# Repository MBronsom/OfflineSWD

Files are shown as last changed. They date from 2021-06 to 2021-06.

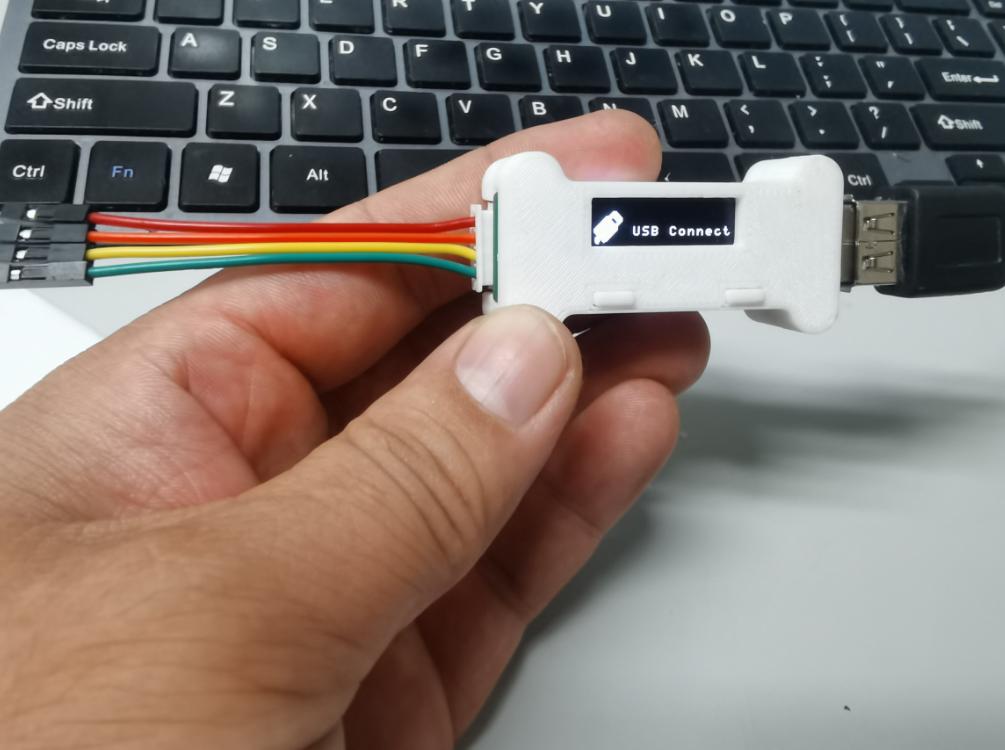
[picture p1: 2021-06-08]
Image/model_1.png

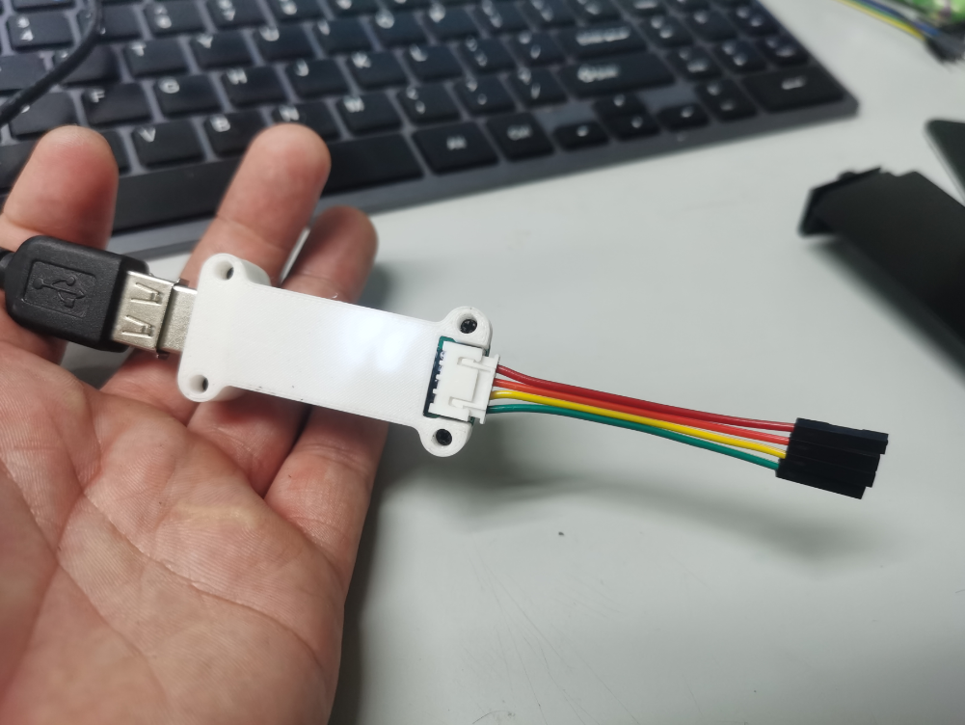
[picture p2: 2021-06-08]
Image/model_2.png

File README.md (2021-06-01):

# SWD离线烧写器
本项目使用STM32F103RET6作为主控，基于ST官方CMSIS-DAP项目进行修改，实现可脱机、可去读保护烧写（因项目暂时只有F103系列脱机烧写需求，所以暂时只添加了F103的烧写算法）。
#### <br>
## 项目功能
#### 1.使用8M FLASH，可使用虚拟U盘向FLASH放置HEX文件或BIN文件进行烧写（BIN较快）
#### 2.可去除目标板的读保护，直接烧写（烧写后可能需要手动重启）
#### 3.支持手动切换模式，使离线烧写器支持DAP仿真
#### 4.安装驱动后可支持虚拟USB转TTL
#### 5.可离线使用串口调试功能（仅支持英文及常用数字符号）
#### <br>
## 使用教程
#### 1.长按SELECT键开机可进入DAP仿真模式，屏幕上显示DAP-CONNECT
#### 2.直接插入电脑USB端口可向离线烧写器放入相关烧写文件，并可使用虚拟串口功能
#### 3.连接目标板开机，选择文件后选择FLASH后即可进行烧写
#### 4.选择“>>”，进入DEBUG MODE后选择ENTER即可进行离线串口调试
#### <br>
## 其他
#### 当前版本项目已包含所有所需外部支持包，无需额外包含其他支持包。
## 项目意见
#### 如果项目有问题或者有新功能需求，欢迎向作者提交意见！
#### 欢迎加入QQ交流群 群号:912015729

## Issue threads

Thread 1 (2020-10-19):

lack of "Driver_USART.h

qiujianqin, 2020-10-19:
..\HARDWARE\DAP\SWO.c(26): error:  #5: cannot open source input file "Driver_USART.h": No such file or directory

MBronsom, 2020-10-19:
请包含ARM CMSIS包中的以下目录
Packs\ARM\CMSIS\5.6.0\CMSIS
Packs\ARM\CMSIS\5.6.0\CMSIS\Include

qiujianqin, 2020-10-19:
按照提示操作已经解决。编译无error

MBronsom, 2020-10-19:
还有其他问题欢迎提出

Closed 2020-10-19.

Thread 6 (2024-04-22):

第一次烧写正常，目标断电后不能再烧写

ssyqwer, 2024-04-22:
第一次烧写正常，目标断电后不能再烧写，程序卡住
    if(0 == swd_flash_syscall_exec(&flash_algo.sys_call_s, flash_algo.init, flash_start, 0, 0, 0))
        {
            return ERROR_INIT;
        }

uint8_t swd_flash_syscall_exec(const program_syscall_t *sysCallParam, uint32_t entry, uint32_t arg1, uint32_t arg2, uint32_t arg3, uint32_t arg4)
{
    DEBUG_STATE state = {{0}, 0};
    // Call flash algorithm function on target and wait for result.
    state.r[0]     = arg1;                   // R0: Argument 1
    state.r[1]     = arg2;                   // R1: Argument 2
    state.r[2]     = arg3;                   // R2: Argument 3
    state.r[3]     = arg4;                   // R3: Argument 4
    state.r[9]     = sysCallParam->static_base;    // SB: Static Base
    state.r[13]    = sysCallParam->stack_pointer;  // SP: Stack Pointer
    state.r[14]    = sysCallParam->breakpoint;     // LR: Exit Point
    state.r[15]    = entry;                        // PC: Entry Point
    state.xpsr     = 0x01000000;          // xPSR: T = 1, ISR = 0

    if (!swd_write_debug_state(&state)) {
        return 0;
    }

    if (!swd_wait_until_halted()) {
        return 0;
    }

    if (!swd_read_core_register(0, &state.r[0])) {
        return 0;
    }

    // Flash functions return 0 if successful.
    if (state.r[0] != 0) {
        return 0;
    }

    return 1;
}

static uint8_t swd_wait_until_halted(void)
{
    // Wait for target to stop
    uint32_t val, i, timeout = MAX_TIMEOUT;

    for (i = 0; i < timeout; i++) {

        if (!swd_read_word(DBG_HCSR, &val)) {
            return 0;
        }
        if (val & S_HALT) {
            return 1;
        }
    }

    return 0;
}
卡在最后一个函数，请问怎么解决

MBronsom, 2024-07-11:
不好意思回复晚了，有点没理解，你的意思是——第一次烧写后，后续都无法继续进行烧写了？还是其他的意思？

ssyqwer, 2024-07-11:
不好意思，这里是我的flash被保护问题，已经解决，感谢感谢

MBronsom, 2024-07-11:
好的👌

Closed 2024-07-11.

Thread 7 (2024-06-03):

离线模式hex转bin有bug

ssyqwer, 2024-06-03:
hex转bin的方式有些问题，如果遇到04类型发生地址跳转，那么按照1k字节写入的数据就会发生地址和数据对不上的情况，应该加上末尾数据填充和新的地址定位

MBronsom, 2024-07-11:
我会进行检查，耐心等待一下～

MBronsom, 2024-07-12:
我看了一下代码，是有对04类型的处理的。如果你那能够复现，能帮忙提供一下烧录的hex文件和导出的Flash，我来检查一下具体问题

ssyqwer, 2024-07-12:
不好意思，hex文件不方便提供，可以给flash最后一页写一些数据然后生成hex文件应该可以复现，我是用j-flash导出的flash和原来的hex做对比

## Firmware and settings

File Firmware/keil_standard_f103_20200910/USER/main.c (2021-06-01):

#include "main.h"

/***********************文件系统使用定义************************/
FIL fnew;													/* file objects */
FILINFO FileInfo;
DIR DirInfo;
FATFS fs;													/* Work area (file system object) for logical drives */
FRESULT Res; 
UINT br, bw;            					/* File R/W count */

/***********************变量定义************************/
char rData[1024] = "";
u8 readflag = 1;
u32 addr = 0;
u32 i = 0;
u32 select = 0;
u8 breakDebug = 0;
u8 debugMode = 0;
uint16_t bytesread;
u8 Logo[] = "BRONSON";

/***********************主函数************************/
 int main(void)
 {
	 Init_device(); //初始化设备
	 Draw_Logo(); //绘制LOGO
	 Draw_Menu(); //绘制菜单
	 while(1);
}
 
/***********************初始化设备************************/
void Init_device()
{
	NVIC_PriorityGroupConfig(NVIC_PriorityGroup_2); //优先级调整
	delay_init(); //初始化延时
	Key_Init(); //按键初始化
	W25QXX_Init(); //初始化Flash芯片
	f_mount(0,&fs); //初始化文件系统
	OLED_Init(); //初始化OLED  
	OLED_Clear(); //清空OLED屏幕
	LED_Init();
	if(Scan_Key() == 1 ){ //按住SELTCT开机进入CMSIS-DAP模式
		Draw_Logo(); //绘制LOGO
		OLED_DrawBMP(0,0,34,34,USBLogo); //绘制图标
		OLED_ShowString(38,1,"DAP Connect",1,0); //绘制提示词
		Init_DAPUSB(); //初始化DAP
		Do_DAPUSB(); //DAP循环
	}
	else{
		Set_System(); //设置USB系统
	  Set_USBClock(); //设置USB时钟
	  USB_Interrupts_Config(); //设置USB中断
	  USB_Init(); //初始化USB
	}
}

/***********************绘制LOGO************************/
void Draw_Logo(){
	 u8 i;
	 for(i=0;i<7;i++){
     OLED_ShowChar(34+i*8,1,Logo[i],1);
	   delay_ms(15);
	 }
	 delay_ms(1000);
	 OLED_Clear();
}

/***********************绘制菜单************************/
void Draw_Menu(){
	if(bDeviceState != UNCONNECTED){
		OLED_DrawBMP(0,0,34,34,USBLogo);
		OLED_ShowString(38,1,"USB Connect",1,0);
	}
  else{
		OLED_DrawBMP(0,0,33,33,FlashLogo);
		//自动烧写模式（将命名为AUTO.bin的文件放入根目录）
		if(f_open(&fnew, (const TCHAR*)"AUTO.bin",FA_READ ) == FR_OK){ 
		  OLED_ShowString(45,-1,"AUTO FLASH",1,0);
		  while(!FLASH_SWD("AUTO.bin")){
		    u8 WaitTips[] = "...";
			  OLED_ShowString(45,1,"          ",1,0);
			  OLED_ShowString(45,2,"WAIT",1,1);
			  for(i=0;i<3;i++){
          OLED_ShowChar(69+i*6,2,WaitTips[i],1);
	        delay_ms(200);
	      }
			  OLED_ShowString(45,2,"       ",1,1);
		  }
			OLED_ShowString(98,2,"BACK",1,1);
			select = 0;
			while(1)
			{
				if(Scan_Key() == 1){
					select ++;
					if(select == 1) {
						OLED_ShowString(98,2,"    ",1,1);
						OLED_ShowString(98,2,"BACK",0,1);
					}
					else{
						OLED_ShowString(98,2,"    ",1,1);
						OLED_ShowString(98,2,"BACK",1,1);
					}
					if(select == 2) select = 0;
				}
				if(Scan_Key() == 2){
					if(select == 1) break;
				}
			}
			OLED_Clear();
		  OLED_DrawBMP(0,0,33,33,FlashLogo);
		}
		Draw_Main(); //进入主菜单
	}
}

/***********************绘制主菜单************************/
void Draw_Main(){
	f_unlink("0:/write.bin");
	if(f_opendir(&DirInfo,(const TCHAR*)"0:") == FR_OK)/* 打开文件夹目录成功，目录信息已经在dir结构体中保存 */
  {
      if(f_readdir(&DirInfo, &FileInfo) == FR_OK)  /* 读文件信息到文件状态结构体中 */
      {
				f_readdir(&DirInfo, &FileInfo);
				OLED_ShowString(45,1,FileInfo.fname,1,1);
			}
	}		
	OLED_ShowString(45,-1,"SELECT HEX",1,0);
	OLED_ShowString(45,0,"----------",1,0);
	OLED_ShowString(110,1,">>",1,1);
	OLED_ShowString(92,2,"FLASH",1,1);
	select = 0;
	while(1)
	{
		if(Scan_Key() == 1){
			select ++;
			if(select == 4) select = 0;
			switch(select){
				case 0:
				  OLED_ShowString(45,1,FileInfo.fname,1,1);
					OLED_ShowString(110,1,">>",1,1);
				  OLED_ShowString(92,2,"FLASH",1,1);
				  break;
				case 1:
				  OLED_ShowString(45,1,FileInfo.fname,0,1);
					OLED_ShowString(110,1,">>",1,1);
				  OLED_ShowString(92,2,"FLASH",1,1);
				  break;
				case 2:
				  OLED_ShowString(45,1,FileInfo.fname,1,1);
					OLED_ShowString(110,1,">>",0,1);
				  OLED_ShowString(92,2,"FLASH",1,1);
				  break;
				case 3:
				  OLED_ShowString(45,1,FileInfo.fname,1,1);
					OLED_ShowString(110,1,">>",1,1);
				  OLED_ShowString(92,2,"FLASH",0,1);
				  break;
			}
		}
		if(Scan_Key() == 2){
			switch(select){
				case 1: //选择文件
					f_readdir(&DirInfo, &FileInfo);
				  OLED_ShowString(45,1,"          ",1, 1);
				  OLED_ShowString(45,1,FileInfo.fname,0,1);
				  OLED_ShowString(110,1,">>",1,1);
				  if(!FileInfo.fname[0]){
						f_opendir(&DirInfo,(const TCHAR*)"0:");
						f_readdir(&DirInfo, &FileInfo);
						f_readdir(&DirInfo, &FileInfo);
						OLED_ShowString(45,1,"          ",1,1);
				    OLED_ShowString(45,1,FileInfo.fname,0,1);
				    OLED_ShowString(110,1,">>",1,1);
					}
					break;
				case 2: //进入调试模式
					select = 0;
					OLED_Clear();
				  OLED_DrawBMP(0,0,32,32,DebugLogo);
				  OLED_ShowString(45,-1,"DEBUG MODE",1,0);
					OLED_ShowString(45,0,"----------",1,0);
				  OLED_ShowString(45,2,"<<",1,1);
				  OLED_ShowString(92,2,"ENTER",1,1);
				  while(1){
						if(Scan_Key() == 1){
							select ++;
							if(select == 3) select = 0;
							switch(select){
								case 0:
									OLED_ShowString(45,2,"<<",1,1);
								  OLED_ShowString(92,2,"ENTER",1,1);
									break;
								case 1:
									OLED_ShowString(45,2,"<<",0,1);
								  OLED_ShowString(92,2,"ENTER",1,1);
									break;
								case 2:
									OLED_ShowString(45,2,"<<",1,1);
								  OLED_ShowString(92,2,"ENTER",0,1);
									break;
							}
							delay_ms(100);
						}
						
						if(Scan_Key() == 2){
							switch(select){
									case 1: //返回上一页面
										OLED_Clear();
										OLED_DrawBMP(0,0,33,33,FlashLogo);
										if(f_opendir(&DirInfo,(const TCHAR*)"0:") == FR_OK)/* 打开文件夹目录成功，目录信息已经在dir结构体中保存 */
										{
											if(f_readdir(&DirInfo, &FileInfo) == FR_OK)  /* 读文件信息到文件状态结构体中 */
											{
												 f_readdir(&DirInfo, &FileInfo);
												 OLED_ShowString(45,1,FileInfo.fname,1,1);
											}
										}		
										OLED_ShowString(45,-1,"SELECT HEX",1,0);
										OLED_ShowString(45,0,"----------",1,0);
										OLED_ShowString(110,1,">>",1,1);
										OLED_ShowString(92,2,"FLASH",1,1);
										select = 0;
										breakDebug = 1;
										break;
									case 2: //确认进入调试模式
										select = 0;
									  debugMode = 1;
										OLED_Clear();
										OLED_ShowString(98,2,"BACK",1,1);
									  while(1)
										{
											if(Scan_Key() == 1){
												select ++;
												if(select == 1) {
													OLED_ShowString(98,2,"    ",1,1);
													OLED_ShowString(98,2,"BACK",0,1);
												}
												else{
													OLED_ShowString(98,2,"    ",1,1);
													OLED_ShowString(98,2,"BACK",1,1);
												}
												if(select == 2) select = 0;
											}
											if(Scan_Key() == 2){
												if(select == 1) break;
											}
										}
										select = 0;
										debugMode = 0;
										OLED_Clear();
										OLED_DrawBMP(0,0,32,32,DebugLogo);
										OLED_ShowString(45,-1,"DEBUG MODE",1,0);
										OLED_ShowString(45,0,"----------",1,0);
										OLED_ShowString(45,2,"<<",1,1);
										OLED_ShowString(92,2,"ENTER",1,1);
										break;
								}
						}
						if(breakDebug){
							breakDebug = 0;
							break;
						}
					}
					break;
				case 3: //进行烧写
					if(strstr(FileInfo.fname,"HEX")) { //HEX文件烧写模式
						OLED_Clear();
		        OLED_DrawBMP(0,0,33,33,FlashLogo);
						if(f_open(&fnew, (const TCHAR*)FileInfo.fname,FA_READ ) == FR_OK){
		          OLED_ShowString(45,-1,"HEX  FLASH",1,0);
							if(HexFormatUncode(FileInfo.fname)!=1){
								OLED_ShowString(45,2,"          ",1,0);
			          OLED_ShowString(45,2,"ERR",1,0);
								select = 0;
			          while(1)
			          {
				          if(Scan_Key() == 1){
					          select ++;
					          if(select == 1) {
						          OLED_ShowString(98,2,"    ",1,1);
						          OLED_ShowString(98,2,"BACK",0,1);
					          }
					          else{
					        	  OLED_ShowString(98,2,"    ",1,1);
						          OLED_ShowString(98,2,"BACK",1,1);
					          }
					           if(select == 2) select = 0;
				          }
				          if(Scan_Key() == 2){
					          if(select == 1) break;
				          }
			          }
			          OLED_Clear();
		            OLED_DrawBMP(0,0,33,33,FlashLogo);
							  if(f_opendir(&DirInfo,(const TCHAR*)"0:") == FR_OK)/* 打开文件夹目录成功，目录信息已经在dir结构体中保存 */
                {
                  if(f_readdir(&DirInfo, &FileInfo) == FR_OK)  /* 读文件信息到文件状态结构体中 */
                  {
				             f_readdir(&DirInfo, &FileInfo);
				             OLED_ShowString(45,1,FileInfo.fname,1,1);
			            }
	              }		
	              OLED_ShowString(45,-1,"SELECT HEX",1,0);
	              OLED_ShowString(45,0,"----------",1,0);
	              OLED_ShowString(110,1,">>",1,1);
	              OLED_ShowString(92,2,"FLASH",1,1);
	              select = 0;
							}
							else{
							  delay_ms(100);
							  OLED_ShowString(45,1,"          ",1,0);
							  OLED_ShowString(45,2,"          ",1,0);
		            while(!FLASH_SWD("write.bin")){
		              u8 WaitTips[] = "...";
			            OLED_ShowString(45,1,"          ",1,0);
			            OLED_ShowString(45,2,"WAIT",1,1);
			            for(i=0;i<3;i++){
                    OLED_ShowChar(69+i*6,2,WaitTips[i],1);
	                  delay_ms(200);
	                }
			            OLED_ShowString(45,2,"       ",1,1);
		            }
								f_unlink("0:/write.bin");
			          OLED_ShowString(98,2,"BACK",1,1);
			          select = 0;
			          while(1)
			          {
				          if(Scan_Key() == 1){
					          select ++;
					          if(select == 1) {
						          OLED_ShowString(98,2,"    ",1,1);
						          OLED_ShowString(98,2,"BACK",0,1);
					          }
					          else{
					        	  OLED_ShowString(98,2,"    ",1,1);
						          OLED_ShowString(98,2,"BACK",1,1);
					          }
					           if(select == 2) select = 0;
				          }
				          if(Scan_Key() == 2){
					          if(select == 1) break;
				          }
			          }
			          OLED_Clear();
		            OLED_DrawBMP(0,0,33,33,FlashLogo);
							  if(f_opendir(&DirInfo,(const TCHAR*)"0:") == FR_OK)/* 打开文件夹目录成功，目录信息已经在dir结构体中保存 */
                {
                  if(f_readdir(&DirInfo, &FileInfo) == FR_OK)  /* 读文件信息到文件状态结构体中 */
                  {
				             f_readdir(&DirInfo, &FileInfo);
				             OLED_ShowString(45,1,FileInfo.fname,1,1);
			            }
	              }		
	              OLED_ShowString(45,-1,"SELECT HEX",1,0);
	              OLED_ShowString(45,0,"----------",1,0);
	              OLED_ShowString(110,1,">>",1,1);
	              OLED_ShowString(92,2,"FLASH",1,1);
	              select = 0;
		          }
					  }
					}
				  else{ //BIN文件烧写模式
						OLED_Clear();
		        OLED_DrawBMP(0,0,33,33,FlashLogo);
						if(f_open(&fnew, (const TCHAR*)FileInfo.fname,FA_READ ) == FR_OK){
		          OLED_ShowString(45,-1,"BIN  FLASH",1,0);
		          while(!FLASH_SWD(FileInfo.fname)){
		            u8 WaitTips[] = "...";
			          OLED_ShowString(45,1,"          ",1,0);
			          OLED_ShowString(45,2,"WAIT",1,1);
			          for(i=0;i<3;i++){
                  OLED_ShowChar(69+i*6,2,WaitTips[i],1);
	                delay_ms(200);
	              }
			          OLED_ShowString(45,2,"       ",1,1);
		          }
			        OLED_ShowString(98,2,"BACK",1,1);
			        select = 0;
			        while(1)
			        {
				        if(Scan_Key() == 1){
					        select ++;
					        if(select == 1) {
						        OLED_ShowString(98,2,"    ",1,1);
						        OLED_ShowString(98,2,"BACK",0,1);
					        }
					        else{
					        	OLED_ShowString(98,2,"    ",1,1);
						        OLED_ShowString(98,2,"BACK",1,1);
					        }
					         if(select == 2) select = 0;
				        }
				        if(Scan_Key() == 2){
					        if(select == 1) break;
				        }
			        }
			        OLED_Clear();
		          OLED_DrawBMP(0,0,33,33,FlashLogo);
							if(f_opendir(&DirInfo,(const TCHAR*)"0:") == FR_OK)/* 打开文件夹目录成功，目录信息已经在dir结构体中保存 */
              {
                if(f_readdir(&DirInfo, &FileInfo) == FR_OK)  /* 读文件信息到文件状态结构体中 */
                {
				           f_readdir(&DirInfo, &FileInfo);
				           OLED_ShowString(45,1,FileInfo.fname,1,1);
			          }
	            }		
	            OLED_ShowString(45,-1,"SELECT HEX",1,0);
	            OLED_ShowString(45,0,"----------",1,0);
	            OLED_ShowString(110,1,">>",1,1);
	            OLED_ShowString(92,2,"FLASH",1,1);
	            select = 0;
		        }
					}
					break;
			}
		}
	}
}

/***********************离线SWD烧写************************/
u8 FLASH_SWD(u8 *File){
	Res = f_open(&fnew, (const TCHAR*)File,FA_READ );
	if ( Res == FR_OK )
	{
		readflag = 1;
	  addr = 0;
		if(swd_init_debug())
		{
				if (target_opt_init() == ERROR_SUCCESS)
				{
					if (target_opt_erase_chip() != ERROR_SUCCESS){
					  return 0;
					}
				}else return 0;
				target_opt_uninit();
			  if (swd_init_debug())
			{
				if (target_flash_init(0x08000000) == ERROR_SUCCESS)
				{
					if (target_flash_erase_chip() == ERROR_SUCCESS)
					{
						while(readflag){
			         f_read(&fnew, rData, 1024, (void *)&bytesread);
			         if(bytesread<1024){
				         readflag = 0;
			         }
								if (target_flash_program_page(0x08000000 + addr, &rData[0], 1024) == ERROR_SUCCESS)
							{
								 u32 progess = (((double)addr/f_size(&fnew))*100);
								 if(progess>=10 && progess<20) {
									 DEBUG_LED = !DEBUG_LED;
									 OLED_ShowString(45,1,"=",1,0);
                   OLED_ShowString(45,2,"10%",1,0);
								 }
								 if(progess>=20 && progess<30) {
									 DEBUG_LED = !DEBUG_LED;
									 OLED_ShowString(45,1,"==",1,0);
                   OLED_ShowString(45,2,"20%",1,0);
								 }
								 if(progess>=30 && progess<40) {
									 DEBUG_LED = !DEBUG_LED;
									 OLED_ShowString(45,1,"===",1,0);
                   OLED_ShowString(45,2,"30%",1,0);
								 }
								 if(progess>=40 && progess<50) {
									 DEBUG_LED = !DEBUG_LED;
									 OLED_ShowString(45,1,"====",1,0);
                   OLED_ShowString(45,2,"40%",1,0);
								 }
								 if(progess>=50 && progess<60) {
									 DEBUG_LED = !DEBUG_LED;
									 OLED_ShowString(45,1,"=====",1,0);
                   OLED_ShowString(45,2,"50%",1,0);
								 }
								 if(progess>=60 && progess<70) {
									 DEBUG_LED = !DEBUG_LED;
									 OLED_ShowString(45,1,"======",1,0);
                   OLED_ShowString(45,2,"60%",1,0);
								 }
								 if(progess>=70 && progess<80) {
									 DEBUG_LED = !DEBUG_LED;
									 OLED_ShowString(45,1,"=======",1,0);
                   OLED_ShowString(45,2,"70%",1,0);
								 }
								 if(progess>=80 && progess<90) {
									 DEBUG_LED = !DEBUG_LED;
									 OLED_ShowString(45,1,"=======",1,0);
                   OLED_ShowString(45,2,"80%",1,0);
								 }
								 if(progess>=90 && progess<100) {
									 DEBUG_LED = !DEBUG_LED;
									 OLED_ShowString(45,1,"=========",1,0);
                   OLED_ShowString(45,2,"90%",1,0);
								 }
							}else return 0;
							addr += 1024;
		        }
						if (swd_init_debug())
		        {
							 DEBUG_LED = 1;
			         swd_set_target_reset(0);//复位运行
							 delay_ms(100);
               OLED_ShowString(45,1,"==========",1,0);
               OLED_ShowString(45,2,"DONE",1,0);
							 return 1;
		        }
						else return 0;
					}else return 0;
				}
				target_flash_uninit();
			}else return 0;
		}else return 0;
	}else return 0;
}

/***********************按键监测************************/
u8 Scan_Key(){
	if(!SELECT){
		delay_ms(35);
		if(!SELECT){
			while(SELECT == !SELECT);
			delay_ms(35);
			return 1;
		}
	}
	if(!OK){
		delay_ms(35);
		if(!OK){
			while(OK == !OK);
			delay_ms(35);
			return 2;
		}
	}
	return 0;
}

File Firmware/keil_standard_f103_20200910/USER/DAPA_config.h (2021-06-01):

/*
* Copyright (c) 2013-2017 ARM Limited. All rights reserved.
*
* SPDX-License-Identifier: Apache-2.0
*
* Licensed under the Apache License, Version 2.0 (the License); you may
* not use this file except in compliance with the License.
* You may obtain a copy of the License at
*
* www.apache.org/licenses/LICENSE-2.0
*
* Unless required by applicable law or agreed to in writing, software
* distributed under the License is distributed on an AS IS BASIS, WITHOUT
* WARRANTIES OR CONDITIONS OF ANY KIND, either express or implied.
* See the License for the specific language governing permissions and
* limitations under the License.
*
* ----------------------------------------------------------------------
*
* $Date:        1. December 2017
* $Revision:    V2.0.0
*
* Project:      CMSIS-DAP Configuration
* Title:        DAP_config.h CMSIS-DAP Configuration File (Template)
*
*---------------------------------------------------------------------------*/

#ifndef __DAP_CONFIG_H__
#define __DAP_CONFIG_H__

#include <stdio.h>
#include <stddef.h>
#include <stdint.h>

extern void vResetTarget(uint8_t bit);

typedef const struct
{
  void  (* LedConnected)  (uint16_t);
  void  (* LedRunning)    (uint16_t);
} CoreDescriptor_t;

extern const CoreDescriptor_t * pCoreDescriptor;

typedef const struct
{
  void    (* UserInit)  (CoreDescriptor_t * core);
  uint32_t  (* UserProcess) (const uint8_t *, uint8_t *);
  void    (* UserAbort) (void);
} UserAppDescriptor_t;

#if  !defined ( BLUEPILL      )  \
  && !defined ( BOARD_V1      ) \
  && !defined ( BOARD_V2      ) \
  && !defined ( STLINK_V20    ) \
  && !defined ( STLINK_V21    ) \
  && !defined ( BOARD_STM32RF ) \
  && !defined ( STLINK_V2A    )
#error "Board undefined"
#endif

//**************************************************************************************************
/** 
\defgroup DAP_Config_Debug_gr CMSIS-DAP Debug Unit Information
\ingroup DAP_ConfigIO_gr 
@{
Provides definitions about:
- Definition of Cortex-M processor parameters used in CMSIS-DAP Debug Unit.
- Debug Unit communication packet size.
- Debug Access Port communication mode (JTAG or SWD).
- Optional information about a connected Target Device (for Evaluation Boards).
*/

#include <stm32f10x.h>

/// Processor Clock of the Cortex-M MCU used in the Debug Unit.
/// This value is used to calculate the SWD/JTAG clock speed.
#define CPU_CLOCK               SystemCoreClock ///< 72MHz, Specifies the CPU Clock in Hz

/// Number of processor cycles for I/O Port write operations.
/// This value is used to calculate the SWD/JTAG clock speed that is generated with I/O
/// Port write operations in the Debug Unit by a Cortex-M MCU. Most Cortex-M processors
/// requrie 2 processor cycles for a I/O Port Write operation.  If the Debug Unit uses
/// a Cortex-M0+ processor with high-speed peripheral I/O only 1 processor cycle might be 
/// requrired.
#define IO_PORT_WRITE_CYCLES    2       ///< I/O Cycles: 2=default, 1=Cortex-M0+ fast I/0

/// Indicate that Serial Wire Debug (SWD) communication mode is available at the Debug Access Port.
/// This information is returned by the command \ref DAP_Info as part of <b>Capabilities</b>.
#define DAP_SWD                 1       ///< SWD Mode:  1 = available, 0 = not available

/// Indicate that JTAG communication mode is available at the Debug Port.
/// This information is returned by the command \ref DAP_Info as part of <b>Capabilities</b>.
#if defined ( BOARD_STM32RF ) \
  || defined ( STLINK_V20 )   \
  || defined ( STLINK_V21 )   \
  || defined ( STLINK_V2A )
#define DAP_JTAG                0       ///< JTAG Mode: 0 = not available, no JTAG pins.
#else
#define DAP_JTAG                1       ///< JTAG Mode: 1 = available, 0 = not available.
#endif

/// Configure maximum number of JTAG devices on the scan chain connected to the Debug Access Port.
/// This setting impacts the RAM requirements of the Debug Unit. Valid range is 1 .. 255.
#define DAP_JTAG_DEV_CNT        8       ///< Maximum number of JTAG devices on scan chain

/// Default communication mode on the Debug Access Port.
/// Used for the command \ref DAP_Connect when Port Default mode is selected.
#define DAP_DEFAULT_PORT        1       ///< Default JTAG/SWJ Port Mode: 1 = SWD, 2 = JTAG.

/// Default communication speed on the Debug Access Port for SWD and JTAG mode.
/// Used to initialize the default SWD/JTAG clock frequency.
/// The command \ref DAP_SWJ_Clock can be used to overwrite this default setting.
#define DAP_DEFAULT_SWJ_CLOCK   10000000 ///< 10MHz, Default SWD/JTAG clock frequency in Hz.

/// Maximum Package Size for Command and Response data.
/// This configuration settings is used to optimized the communication performance with the
/// debugger and depends on the USB peripheral. Change setting to 1024 for High-Speed USB.
#define DAP_PACKET_SIZE         64      ///< USB: 64 = Full-Speed, 1024 = High-Speed.
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

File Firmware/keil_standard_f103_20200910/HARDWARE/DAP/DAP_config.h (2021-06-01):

#ifndef __DAP_CONFIG_H__
#define __DAP_CONFIG_H__


#define CPU_CLOCK               72000000        ///< Specifies the CPU Clock in Hz

#define IO_PORT_WRITE_CYCLES    2               ///< I/O Cycles: 2=default, 1=Cortex-M0+ fast I/0

#define DAP_SWD                 1               ///< SWD Mode:  1 = available, 0 = not available

#define DAP_JTAG                0               ///< JTAG Mode: 0 = not available

#define DAP_JTAG_DEV_CNT        8               ///< Maximum number of JTAG devices on scan chain

#define DAP_DEFAULT_PORT        1               ///< Default JTAG/SWJ Port Mode: 1 = SWD, 2 = JTAG.

#define DAP_DEFAULT_SWJ_CLOCK   4000000         ///< Default SWD/JTAG clock frequency in Hz.


/// Maximum Package Size for Command and Response data.
#define DAP_PACKET_SIZE         64              ///< USB: 64 = Full-Speed, 1024 = High-Speed.

/// Maximum Package Buffers for Command and Response data.
#define DAP_PACKET_COUNT        1              ///< Buffers: 64 = Full-Speed, 4 = High-Speed.

/// Indicate that UART Serial Wire Output (SWO) trace is available.
#define SWO_UART                0               ///< SWO UART:  1 = available, 0 = not available

#define SWO_UART_MAX_BAUDRATE   10000000U       ///< SWO UART Maximum Baudrate in Hz

/// Indicate that Manchester Serial Wire Output (SWO) trace is available.
#define SWO_MANCHESTER          0               ///< SWO Manchester:  1 = available, 0 = not available

#define SWO_BUFFER_SIZE         4096U           ///< SWO Trace Buffer Size in bytes (must be 2^n)

/// Debug Unit is connected to fixed Target Device.
#define TARGET_DEVICE_FIXED     0               ///< Target Device: 1 = known, 0 = unknown;


//**************************************************************************************************
/**
JTAG I/O Pin                 | SWD I/O Pin          | CMSIS-DAP Hardware pin mode
---------------------------- | -------------------- | ---------------------------------------------
TCK: Test Clock              | SWCLK: Clock         | Output Push/Pull
TMS: Test Mode Select        | SWDIO: Data I/O      | Output Push/Pull; Input (for receiving data)
TDI: Test Data Input         |                      | Output Push/Pull
TDO: Test Data Output        |                      | Input
nTRST: Test Reset (optional) |                      | Output Open Drain with pull-up resistor
nRESET: Device Reset         | nRESET: Device Reset | Output Open Drain with pull-up resistor

DAP Hardware I/O Pin Access Functions
*/
#include "stm32f10x.h"


// Configure DAP I/O pins ------------------------------


#define GPIO_INIT(port, data)	GPIO_Init(port, (GPIO_InitTypeDef *)&data)
#define PIN_MODE_MASK(pin)		(((uint32_t)0x0F) << ((pin) << 2))
#define PIN_MODE(mode,pin)		(((uint32_t)mode) << ((pin) << 2))
#define PIN_MASK(pin)			    (((uint16_t)0x01) << (pin))

#define PIN_nRESET				PIN_MASK(PIN_nRESET_PIN)
#define PIN_SWDIO_TMS			PIN_MASK(PIN_SWDIO_TMS_PIN)
#define PIN_SWCLK_TCK			PIN_MASK(PIN_SWCLK_TCK_PIN)

/*********************这里为SWD引脚定义**********************
*无需配置引脚时钟，引脚的时钟在SWD_PORT_RCC_INIT()自动初始化
*************************************************************/
// SWDIO/TMS Pin
#define PIN_SWDIO_TMS_PORT		GPIOA
#define PIN_SWDIO_TMS_PIN			9

// SWCLK/TCK Pin
#define PIN_SWCLK_TCK_PORT		GPIOA
#define PIN_SWCLK_TCK_PIN			10

// nRESET Pin
//#define PIN_nRESET_PORT     GPIOB   //预留硬件复位引脚
//#define PIN_nRESET_PIN			0


static __inline uint32_t PIN_SWCLK_TCK_IN(void)
{
  return (PIN_SWCLK_TCK_PORT->ODR & PIN_SWCLK_TCK) ? 1 : 0;
}

static __inline void PIN_SWCLK_TCK_SET(void)
{
    PIN_SWCLK_TCK_PORT->BSRR = PIN_SWCLK_TCK;
}

static __inline void PIN_SWCLK_TCK_CLR(void)
{
    PIN_SWCLK_TCK_PORT->BRR = PIN_SWCLK_TCK;
}


// SWDIO/TMS Pin I/O --------------------------------------

// Current status of the SWDIO/TMS DAP hardware I/O pin
static __inline uint32_t PIN_SWDIO_TMS_IN(void)
{
   return (PIN_SWDIO_TMS_PORT->IDR & PIN_SWDIO_TMS) ? 1 : 0;
}

static __inline void PIN_SWDIO_TMS_SET(void)
{
   PIN_SWDIO_TMS_PORT->BSRR = PIN_SWDIO_TMS;
}

static __inline void PIN_SWDIO_TMS_CLR(void)
{
    PIN_SWDIO_TMS_PORT->BRR  = PIN_SWDIO_TMS;
}


static __inline uint32_t PIN_SWDIO_IN(void)
{
    if (PIN_SWDIO_TMS_PORT->IDR & PIN_SWDIO_TMS)
        return 1;
    return 0;
}

static __inline void PIN_SWDIO_OUT(uint32_t bit)
{
     if (bit & 1)
        PIN_SWDIO_TMS_PORT->BSRR = PIN_SWDIO_TMS;
    else
        PIN_SWDIO_TMS_PORT->BRR  = PIN_SWDIO_TMS;
}


//	For fast switch between input and output mode
//	without GPIO_Init call
#if (PIN_SWDIO_TMS_PIN >= 8)
#define PIN_SWDIO_TMS_OUT_DISABLE()							\
		do {																				\
			PIN_SWDIO_TMS_PORT->CRH = (PIN_SWDIO_TMS_PORT->CRH & ~PIN_MODE_MASK(PIN_SWDIO_TMS_PIN - 8)) | PIN_MODE(0x8, PIN_SWDIO_TMS_PIN - 8);	\
			PIN_SWDIO_TMS_PORT->BSRR = PIN_SWDIO_TMS;	\
		} while (0)
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

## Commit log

2021-06-01 修复了PCB原理图中晶振大小标注错误的问题(正确大小为8Mhz)
    [0.91-oled.PcbLib, 0.91-oled.SCHLIB, OfflineSWD.PcbDoc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]
2021-06-01 加入FlashAlgo工具(将FLM文件拖至工具即可生成)
2021-06-08 添加烧写器外壳文件（外壳支持:HQB）
2021-07-13 项目结构重新规范化设计
    1.重构了项目结构
    2.[Hardware]添加了旧版本PCB的一些3D模型
    [0.91-oled.PcbLib, 0.91-oled.SCHLIB, OfflineSWD.PcbDoc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]
2021-07-13 [Hardware]添加F401烧写器相关文件
    [f103ret6_w25q64_20200910.SchDoc, f401ccu6_w25q64_20210612.PcbDoc, f401ccu6_w25q64_20210612.PrjPcb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]
2021-07-13 [Hardware]绘制F401相关PCB文件
    [5PinHeader.PcbLib, f401ccu6_w25q64_20210612.PrjPcb, f401ccu6_w25q64_20210612.SchDoc]
2021-07-13 添加Apache 2.0开源协议
2021-07-13 [Hardware]F401烧写器相关丝印添加
    [f401ccu6_w25q64_20210612.PrjPcb, f401ccu6_w25q64_20210612.SchDoc]
2021-07-13 修复了一些PCB当中的BUG，并准备加入F401工程
    1.[Hardware]F401工程中修复USB中DM-DP引脚接反的错误
    2.[Firmware]修改了F103中的工程名称
    [f401ccu6_w25q64_20210612.PcbDoc, f401ccu6_w25q64_20210612.PrjPcb, f401ccu6_w25q64_20210612.SchDoc]
2021-07-17 [Hardware]添加对之前F103版本PCB的一些修改
    [f103ret6_w25q64_20210714.PcbDoc, f103ret6_w25q64_20210714.PrjPcb, f103ret6_w25q64_20210714.SchDoc]
